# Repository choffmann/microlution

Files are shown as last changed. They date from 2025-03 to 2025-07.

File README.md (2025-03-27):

# Microlution

Vollautomatisierter Probenwechsler - ein haufen an Proben wird nach und nach in das Microskop befüllt,
welche automatisch abgelichtet werden und durch stiching aufgewertet werden.

- Display mit Fortschrittsbalken
- Buttons zum starten/stopen
- Stisching
  - hardwaremäßige abfahren
  - Bilder aufnehmen
  - In Software zusammensetzen
- Webserver
  - Zugriff auf Daten
  - Steuerung
  - Video Stream
- Besserer Autofocus
- Rust?

## Hardware

- microskope setup
- joystick
- taster
- Display
- (Vacum pumpe)
- extra stepper motoren

## Kommunikation

Discord
WhatsApp

## Code

GitHub -> Alles an Software
Workflow zum testen

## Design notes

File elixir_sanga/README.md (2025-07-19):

# ElixirSanga

Elixir library for communicating with the Sanga motor controller board via serial port.

## Communication Modes

This library supports two different communication modes:

### 1. Persistent Connection Mode (Fast, Exclusive Access)
Maintains a persistent connection to the serial port for high-frequency communication. This is faster but holds an exclusive lock on the serial port.

```elixir
# Start the persistent connection
{:ok, _pid} = Sanga.Board.start_link()

# Send commands
{:ok, version} = Sanga.Board.query("v")
{:ok, result} = Sanga.Board.multi_query(["n_motors 4", "mr 0 0 0 100", "n_motors 3"])
{:ok, result} = Sanga.Board.move_slider(100)

# Stop the connection
:ok = Sanga.Board.stop()
```

### 2. Safe Connection Mode (Slower, Shared Access)
Opens and closes the connection for each operation, allowing other services to access the serial port. This is slower due to connection overhead but allows multiple services to communicate with the motor controller.

```elixir
# No need to start/stop - each command manages its own connection
{:ok, version} = Sanga.Board.safe_query("v")
{:ok, result} = Sanga.Board.safe_multi_query(["n_motors 4", "mr 0 0 0 100", "n_motors 3"])
{:ok, result} = Sanga.Board.safe_move_slider(100)

# Stage control methods
{:ok, result} = Sanga.Board.safe_move_stage_x(10.5)    # Move stage in X direction
{:ok, result} = Sanga.Board.safe_move_stage_y(-5.2)    # Move stage in Y direction  
{:ok, result} = Sanga.Board.safe_move_stage_z(2.0)     # Move stage in Z direction
{:ok, result} = Sanga.Board.safe_release_stage()       # Release motor holding torque
{:ok, result} = Sanga.Board.safe_zero_stage()          # Zero/home the stage
```

### When to Use Each Mode

- **Persistent Mode**: Use when you need exclusive access and high-frequency communication
- **Safe Mode**: Use when other services also need to communicate with the motor controller

## Installation

If [available in Hex](https://hex.pm/docs/publish), the package can be installed
by adding `elixir_sanga` to your list of dependencies in `mix.exs`:

```elixir
def deps do
  [
    {:elixir_sanga, "~> 0.1.0"}
  ]
end
```

Documentation can be generated with [ExDoc](https://github.com/elixir-lang/ex_doc)
and published on [HexDocs](https://hexdocs.pm). Once published, the docs can
be found at <https://hexdocs.pm/elixir_sanga>.

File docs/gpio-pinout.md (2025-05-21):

| GPIO | Pin # | Funktion | Verwedt für | Schnittstelle |
| --- | ----- | --- | --- | --- |
| 3v3 Power | 1 | Stromversorgung | Rotary Encoder VCC | - |
| GND | 6 | Masse | Rotary Encoder GND | - |
| GPIO17 | 11 | Eingang | Rotary Encoder DT  | GPIO |
| GPIO18 | 12 | Eingang | Rotary Encoder CLK | GPIO |
| GPIO27 | 13 | Eingang | Rotary Encoder SW  | GPIO |
| 3v3 Power | 17 | Stromversorgung | TFT VCC | - |
| GND | 9 | Masse | TFT GND | - |
| GPIO10 | 19 | SPI MOSI | TFT MOSI | SPI |
| GPIO11 | 23 | SPI SCK | TFT SCK | SPI |
| GPIO16 | 36 | Ausgang | TFT Backlight LED  | GPIO |
| GPIO9 | 21 | SPI MISO | TFT MISO | SPI |
| GPIO24 | 18 | Ausgang | TFT DC | GPIO |
| GPIO25 | 22 | Ausgang | TFT RST | GPIO |
| GPIO8 | 24 | SPI CS0 | TFT CS | SPI |
| GPIO 14 | 8 | UART TX | Sangaboard | UART |
| GPIO 15 | 10 | UART RX | Sangaboard | UART |

Mögliche Konflikte mit dem Sangaboard:

- **GPIO24** und **GPIO25** sind nur dann zu verwenden, wenn keine Firmware-Upgrades für das Sangaboard geplant sind.
- **GPIO14** und **GPIO15** (UART) sollten nicht verwendet werden, diese sind für die Kommunikation mit dem Sangaboard reserviert.

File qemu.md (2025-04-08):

```bash
# mount /boot
sudo mount -o loop,offset=4194304 2023-04-13-raspbian-openflexure-buster-armhf.img /mnt/rpi-boot
# mount /
sudo mount -v -o offset=266338304 -t ext4 2023-04-13-raspbian-openflexure-buster-armhf.img /mnt/rpi-boot
```

offset => `fdisk -l <img>` => anfang _einheit sektoren. (8192_ 512 = 4194304)

Weitere benötigte Dateien, welche in /boot zu finden sind:

- `bcm2710-rpi-3-b.dtb`
- `kernel8.img`

### User password reset

`/` von img mounten und in `/etc/passwd` das `...:x:...` entfernen. Das entfernen von `:x:` entfernt das kennwort vom benutzer.

```bash
# root:x:0:0:root:/root:/bin/bash
#      ^--- entfernen
# root::0:0:root:/root:/bin/bash
```

## QEMU

`CTRL-a + c` => qemu console
`CTRL-a + x` => qemu terminate
`system_powerdown` => shutdown guest

Resize img für qemu (qemu mag anscheind nur images in der größe `^2`)

```bash
qemu-img resize 2023-04-13-raspbian-openflexure-buster-armhf.img 8G
```

Image Partition muss dennoch angepasst werden

```bash
qemu-system-aarch64 \
    -machine raspi3b \
    -cpu cortex-a72 \
    -nographic \
    -m 1G \
    -smp 4 \
    -dtb bcm2710-rpi-3-b.dtb \
    -kernel kernel8.img \
    -append "rw earlyprintk loglevel=8 console=ttyAMA0,115200 dwc_otg.lpm_enable=0 root=/dev/mmcblk0p2 rootdelay=1" \
    -netdev user,id=net0,hostfwd=tcp::5000-:5000,hostfwd=tcp::2222-:22 \
    -device usb-net,netdev=net0 \
    -device usb-host,hostbus=5,hostaddr=6 \
    -sd 2023-04-13-raspbian-openflexure-buster-armhf.img
```

### Resize partitions

```bash
sudo fdisk /dev/mmcblk0
```

```
Command (m for help): d
Partition number (1,2, default 2): 2
Partition 2 has been deleted.

Command (m for help): n
Partition type
   p   primary (1 primary, 0 extended, 3 free)
   e   extended (container for logical partitions)
Select (default p): e
Partition number (2-4, default 2): 2
First sector (2048-16777215, default 2048): 520192
Last sector, +/-sectors or +/-size{K,M,G,T,P} (520192-16777215, default 16777215):

Created a new partition 2 of type 'Extended' and of size 7.8 GiB.
Partition #2 contains a ext4 signature.

Do you want to remove the signature? [Y]es/[N]o: n
```

```bash
sudo resize2fs /dev/mmcblk0p2
```

## OpenFlexure Server in qemu

mit `DummyCamera` kann `vchiq` (Pi Kamera) umgehen und `DummyStage` (Motoren) deaktiviert werden.

```json
{
  "camera": {
    "type": "DummyCamera"
  },
  "stage": {
    "type": "DummyStage",
    "port": null
  }
}
```

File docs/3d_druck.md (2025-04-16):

# Tracking of 3d printed parts

## Original Parts [download link](https://build.openflexure.org/openflexure-microscope/v7.0.0-beta3/source.zip)
| Part Name | Required Quantity | Printed Quantity | File | Extra Details |
|---|---|---|---|---|
| Actuator assembly tools (nut tool, band tool, and band tool cover) | 1 | - | [actuator_assembly_tools.stl] | |
| Lens tool | 1 | - | [lens_tool.stl] | |
| Main body | 1 | 1 | [main_body.stl] | The smart brim may require custom print settings. |
| Cable tidy caps | 3 | - | [cable_tidies.stl] | |
| Sample clips | 2 | - | [sample_clips.stl] | |
| Microscope stand | 1 | 1 | [microscope_stand.stl] | |
| Electronics drawer | 1 | - | [electronics_drawer-pi4_sanga_stack_11mm.stl] | For Pi 4 and HAT-style Sangaboard with 11mm tall headers. For other combinations, refer to customization page |
| Small gears | 3 | - | [small_gears.stl] | |
| Illumination dovetail | 1 | - | [illumination_dovetail.stl] | |
| Condenser arm | 1 | - | [condenser.stl] | |
| Condenser board spacer | 1 | - | [condenser_board_spacer.stl] | |
| Condenser lid | 1 | - | [condenser_lid.stl] | |
| Illumination thumbscrew | 1 | - | [illumination_thumbscrew.stl] | |
| Large gears | 3 | - | [large_gears.stl] | |
| Feet | 3 | - | [feet.stl] | |
| Optics module | 1 | - | [optics_picamera_2_rms_f50d13.stl] | Must be printed in black! |
| Pi camera cover | 1 | - | [picamera_2_cover.stl] | |

## Modified Parts

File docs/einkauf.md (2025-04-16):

# Liste an bestellten Teilen
## Bestellung 1
| Item | Quantity | angekommen | Link |
|---|---|---|---|
| **Shop1** | | | |
| Nema17 | 1 | - [ ] | [Link](https://www.roboter-bausatz.de/p/act-nema-17-schrittmotor-17hs3404l23p1-x1-12v-0.4a-34mm) |
| TMC2209 Stepper Driver | 1 | - [ ] | [Link](https://www.roboter-bausatz.de/p/mks-tmc2209-schrittmotortreiber) |
| Vierkant Mutter | 20? | - [ ] | [Link](https://www.roboter-bausatz.de/p/m3-vierkantmutter-5-5x2-5mm) |
| belt | 1 | - [ ] | [Link](https://www.roboter-bausatz.de/p/yourdroid-gt2-zahnriemen-offen-6mm-1-meter-faserverstaerkt) |
| motor pulley | 1 | - [ ] | [Link](https://www.roboter-bausatz.de/p/gt2-riemenscheibe-20-zaehne-5mm-bohrung-fuer-6mm-riemen) |
| idler pulley | 1 | - [ ] | [Link](https://www.roboter-bausatz.de/p/gt2-zahnriemen-flachriemenscheibe-3mm-bohrung-fuer-6mm-zahnriemen) |
| Display 2,4 Zoll | 1 | - [ ] | [Link](https://www.roboter-bausatz.de/p/2-4-tft-lcd-display-modul-ili9341-240x320) |
| Rotaryencoder | 1 | - [ ] | [Link](https://www.roboter-bausatz.de/p/drehencoder-drehregler-ky-040-modul) |
| Navigation module | 1 | - [ ] | [Link](https://www.roboter-bausatz.de/p/joystick-5-richtungen-navigation-button-modul) |
| mosfet modul | 2 | - [ ] | [Link](https://www.roboter-bausatz.de/p/mosfet-irf520-treibermodul) |
| jumper kabel | 1 | - [ ] | [Link](https://www.roboter-bausatz.de/p/dupont-jumper-kabel-3-x-40-pin-20-cm-m2m-f2m-f2f) |
| **Shop2** | | | |
| Elektromagnet 20x15 | 4 | - [ ] | [Link](https://funduinoshop.com/elektronische-module/sonstige/elektromagnete/elektromagnet-dc12v-wf-p20/15-2-5kg) |

## Bestellung 2
Noch nichts geplant.  
Dient um Teile nachzukaufen die im Laufe des Projektes als Notwendig erkannt werden.

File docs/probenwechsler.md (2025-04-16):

# Doku des Probenwechslers
## Ursprünglicher Zustand
Proben werden per Hand auf der Stage platziert. Proben werden mit Clips fixiert an der Stage. Und danach per Hand entfernt.
## Gewünschter Zustand
Ein System das mehrere (ung.2-5) 75x25mm Proben über die Stage bewegt. Die Bewegung passiert automatisiert. 

## Herausforderungen
1. Bewegung der Stage darf nicht eingeschränkt werden
2. Probenarretierung
3. Motorsteuerung
4. OpenSCAD

## Designs
1. Slide befestigt an Stage (ersetzt wahrscheinlich keine der achsen, bewegung vorne/hinten benutzt x und y motor)
2. Magazin mit Bewegungsarm. Bewegt einzelne Proben von einem Magazin auf die Stage und weg.
3. Magazin mit Dreharm

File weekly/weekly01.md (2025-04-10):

---
date: 10.04.2025
---

## Stitching #1

@fiete

**Recherche**

Es gibt zwei optionen

- Automatische kantenerkennung
- Manuelle zusammenfügeng durch x und y werte + kanten aufweichen (feathering, blending)

Wie implementieren wenn kein null punkt möglich? Beides verwenden?

Andere variante für Nullpunkt wäre das erste Bild von dem man aus geht

**Nächster Schritt**

- [ ] Beispieldaten: Ziehen oder manuell erstellen?

## Einkauf #8

@niklas

Bestellliste wurde ertsellt, wird noch überarbeitet <https://docs.google.com/spreadsheets/d/19g0L3icq9huzQc2gaac8i5vfSKruxdHDz61IX5RrIJk/edit?usp=sharing>

## Gesamtsystem

@cedrik

System wurde testweise aufgesetzt (emuliert in qemu, da kein Pi zur verfügung), sowie generelle recherche zum System

**Nächster Schritt**

- [ ] Software aufsetzen auf einem Pi
- [ ] Microsope drucken und bauen

## Probenwechsler #4

@niklas

Erster Prototyp wurde erstellt, kleine Magnete sind schwach, große Magnete sind zu groß.

**Nächster Schritt**

- [ ] 3D Sourcefile vom Microsope anpassen für unser System
- [ ] Mit echte Probe austesten zu heben

## Organisation

@alle

- [ ] Noch nicht zugeteilte aufgaben zuteilen

## Hardware Input #11

Noch nicht gestartet

## Web UI #13

Noch nicht gestartet

## Webserver #9

Noch nicht gestartet

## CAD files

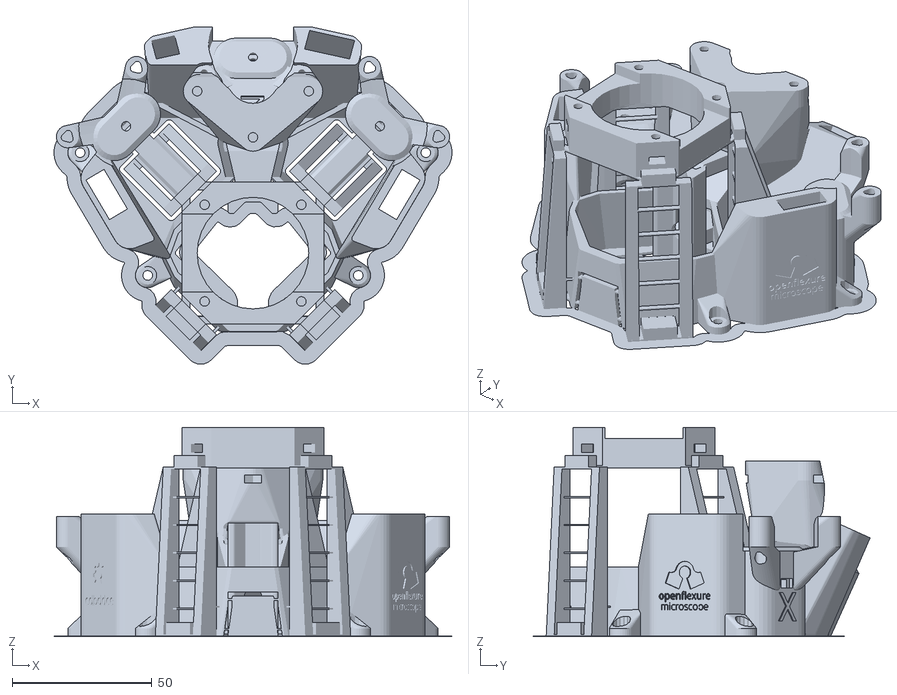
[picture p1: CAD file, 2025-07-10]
custom-stl-parts/openflexure_body_modified.stl
142.6 x 120.9 x 75.0

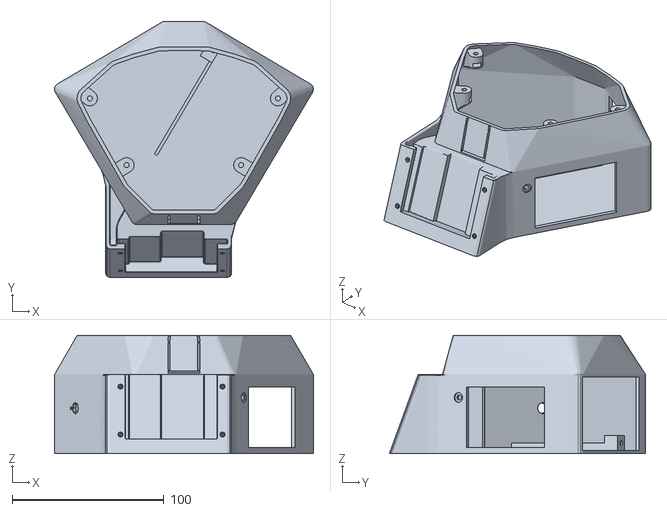
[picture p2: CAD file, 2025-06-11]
custom-stl-parts/microscope_stand_jw_v2.stl
170.6 x 168.9 x 78.0

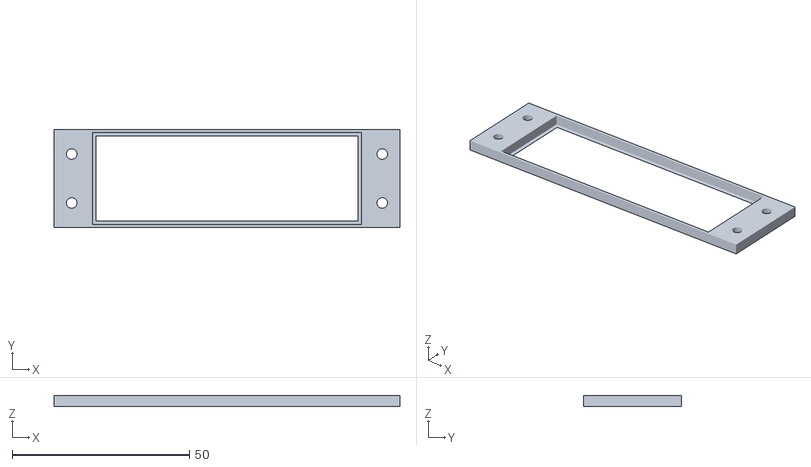
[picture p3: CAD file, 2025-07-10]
custom-stl-parts/MicroSlide/MicroSlide_follower_sample holder.stl
97.6 x 27.6 x 3.10

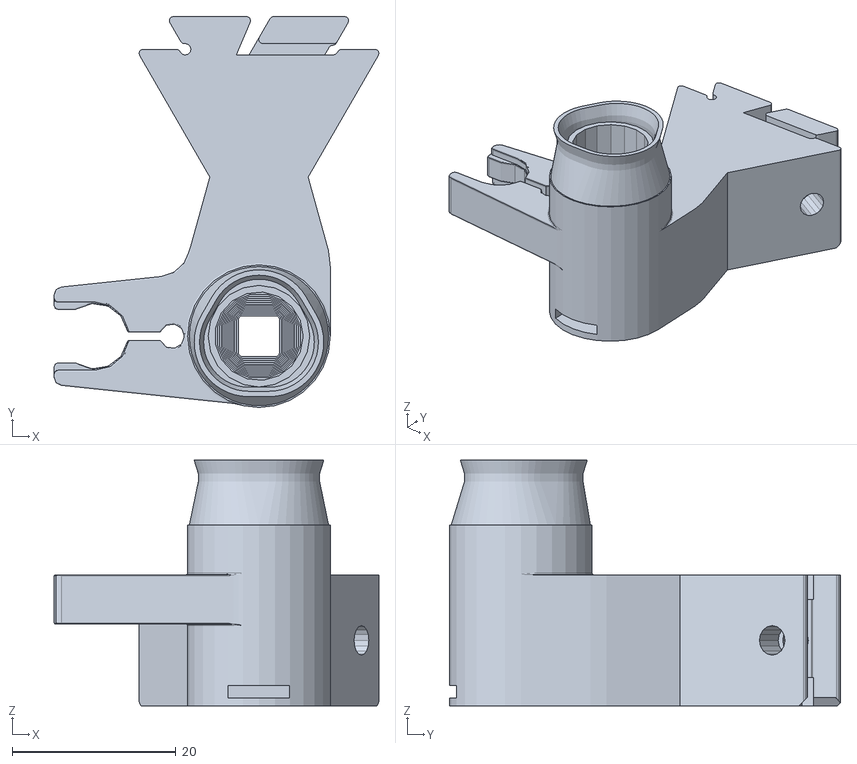
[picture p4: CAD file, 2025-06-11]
custom-stl-parts/condensersolid.stl
39.6 x 47.7 x 30.0

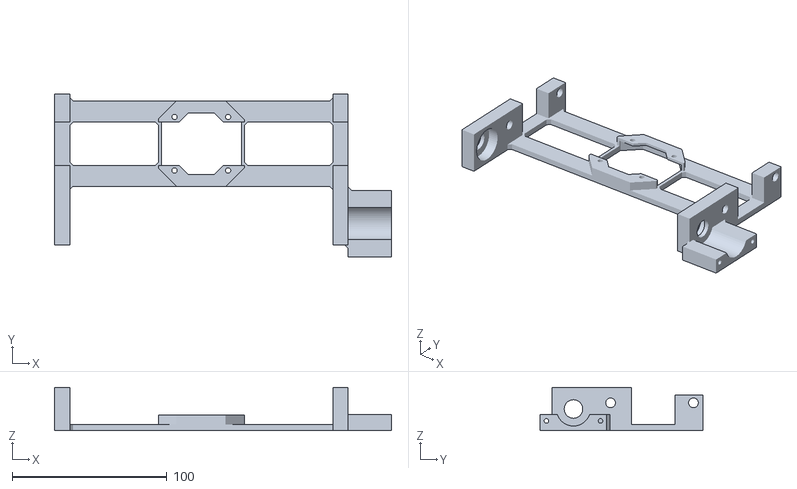
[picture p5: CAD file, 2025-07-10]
custom-stl-parts/MicroSlide/MicroSlide_Platformbracket.stl
218.0 x 105.1 x 28.0

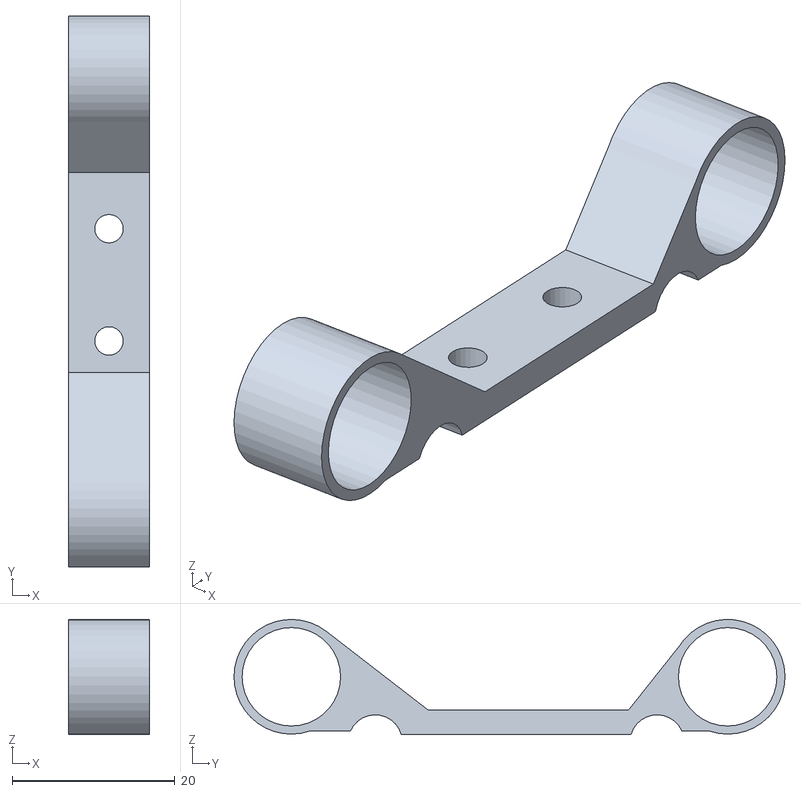
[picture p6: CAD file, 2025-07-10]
custom-stl-parts/MicroSlide/MicroSlide_follower_stabilizer.stl
10.0 x 67.7 x 14.1

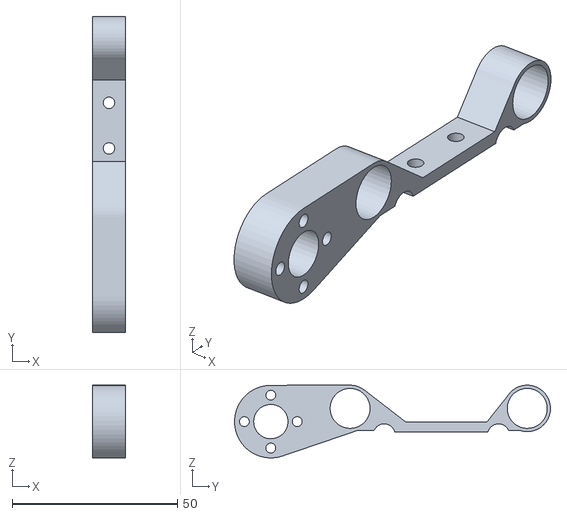
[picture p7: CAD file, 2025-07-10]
custom-stl-parts/MicroSlide/MicroSlide_follower_screw_connection.stl
10.0 x 95.7 x 22.0

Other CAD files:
CAD-Designs/MicroSlide v6 (Fusion360).f3z

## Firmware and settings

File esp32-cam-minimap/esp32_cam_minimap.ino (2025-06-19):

#include "esp_camera.h"
#include <WiFi.h>
#include <WebServer.h>

const char* ssid = "Microlution";
const char* password = "knorke123";

WiFiClient streamClient;
bool isStreaming = false;

// Set camera model (AI Thinker)
#define PWDN_GPIO_NUM     32
#define RESET_GPIO_NUM    -1
#define XCLK_GPIO_NUM      0
#define SIOD_GPIO_NUM     26
#define SIOC_GPIO_NUM     27

#define Y9_GPIO_NUM       35
#define Y8_GPIO_NUM       34
#define Y7_GPIO_NUM       39
#define Y6_GPIO_NUM       36
#define Y5_GPIO_NUM       21
#define Y4_GPIO_NUM       19
#define Y3_GPIO_NUM       18
#define Y2_GPIO_NUM        5
#define VSYNC_GPIO_NUM    25
#define HREF_GPIO_NUM     23
#define PCLK_GPIO_NUM     22

WebServer server(80);

void startCamera() {
  camera_config_t config;
  config.ledc_channel = LEDC_CHANNEL_0;
  config.ledc_timer = LEDC_TIMER_0;
  config.pin_d0 = Y2_GPIO_NUM;
  config.pin_d1 = Y3_GPIO_NUM;
  config.pin_d2 = Y4_GPIO_NUM;
  config.pin_d3 = Y5_GPIO_NUM;
  config.pin_d4 = Y6_GPIO_NUM;
  config.pin_d5 = Y7_GPIO_NUM;
  config.pin_d6 = Y8_GPIO_NUM;
  config.pin_d7 = Y9_GPIO_NUM;
  config.pin_xclk = XCLK_GPIO_NUM;
  config.pin_pclk = PCLK_GPIO_NUM;
  config.pin_vsync = VSYNC_GPIO_NUM;
  config.pin_href = HREF_GPIO_NUM;
  config.pin_sscb_sda = SIOD_GPIO_NUM;
  config.pin_sscb_scl = SIOC_GPIO_NUM;
  config.pin_pwdn = PWDN_GPIO_NUM;
  config.pin_reset = RESET_GPIO_NUM;
  config.xclk_freq_hz = 20000000;
  config.pixel_format = PIXFORMAT_JPEG;

  config.frame_size = FRAMESIZE_QVGA;
  config.jpeg_quality = 10;
  config.fb_count = 2;

  esp_err_t err = esp_camera_init(&config);
  if (err != ESP_OK) {
    while (true) delay(1000);
  }
}

void stream() {
  streamClient = server.client();
  isStreaming = true;

  String response = "HTTP/1.1 200 OK\r\n";
  response += "Content-Type: multipart/x-mixed-replace; boundary=frame\r\n\r\n";
  streamClient.print(response);
}

void capture() {
  camera_fb_t *frameBuffer = esp_camera_fb_get();
  if (!frameBuffer) {
    server.send(500, "text/plain", "Camera capture failed");
    return;
  }

  server.setContentLength(frameBuffer->len);
  server.send(200, "image/jpeg", "");

  WiFiClient client = server.client();
  client.write(frameBuffer->buf, frameBuffer->len);

  esp_camera_fb_return(frameBuffer);
}

void setup() {
  Serial.begin(115200);
  delay(1000);

  WiFi.begin(ssid, password);
  while (WiFi.status() != WL_CONNECTED) {
    delay(500);
  }


  startCamera();

  server.on("/stream", HTTP_GET, stream);
  server.on("/capture", HTTP_GET, capture);
  server.begin();
}

void loop() {
  server.handleClient();

  if (isStreaming && streamClient.connected()) {
    camera_fb_t *frameBuffer = esp_camera_fb_get();
    if (frameBuffer) {
      streamClient.write(frameBuffer->buf, frameBuffer->len);
      esp_camera_fb_return(frameBuffer);
    }
    delay(100);
  } else if (isStreaming) {
    isStreaming = false;
  }
}

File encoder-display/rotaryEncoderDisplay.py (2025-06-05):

import RPi.GPIO as GPIO
import time
import requests
import board
import busio
import digitalio
import displayio
from adafruit_ili9341 import ILI9341
from adafruit_display_text import label
import terminalio

displayio.release_displays()

# GPIO-Pin-Config Roatary encoder
CLK = 17
DT = 18
SW = 27

# OpenFlexure Server URL
URL = "http://localhost:5000/api/v2/actions/stage/move/"
STEP_SIZES = {'z': 200, 'x': 200, 'y': 200}

# SPI-Setup
spi = busio.SPI(clock=board.SCK, MOSI=board.MOSI)

backlight = digitalio.DigitalInOut(board.D16)
backlight.direction = digitalio.Direction.OUTPUT
backlight.value = True

display_bus = displayio.FourWire(
    spi,
    command=board.D24,
    chip_select=board.D8,
    reset=board.D25
)

display = ILI9341(display_bus, width=320, height=240, rotation= 180)

# GUI
splash = displayio.Group()
display.root_group = splash

# Achse-Label
label_static = label.Label(
    terminalio.FONT,
    text="Achse: ",
    color=0xFFFFFF,
    x=260,
    y=10
)

# Achsen-Kennung
label_dynamic = label.Label(
    terminalio.FONT,
    text="Z",
    color=0xFFFFFF,
    background_color=0x0000FF,
    x=300,
    y=10
)

splash.append(label_static)
splash.append(label_dynamic)

mode_colors = {'z': 0x0000FF, 'x': 0x00AA00, 'y': 0xFF0000}

# GPIO Setup Rotary-Encoder
GPIO.setmode(GPIO.BCM)
GPIO.setup(CLK, GPIO.IN, pull_up_down=GPIO.PUD_UP)
GPIO.setup(DT, GPIO.IN, pull_up_down=GPIO.PUD_UP)
GPIO.setup(SW, GPIO.IN, pull_up_down=GPIO.PUD_UP)

last_clk_state = GPIO.input(CLK)
modes = ['z', 'x', 'y']
mode_index = 0

print(f"Aktueller Modus: {modes[mode_index].upper()}")

def update_display_mode():
    axis = modes[mode_index]
    label_dynamic.text = axis.upper()
    label_dynamic.background_color = mode_colors[axis]

def move_axis(axis, amount):
    payload = {axis: amount, 'absolute': False}
    try:
        response = requests.post(URL, json=payload, timeout=1)
        if response.status_code == 201:
            print(f"{axis.upper()} bewegt um {amount} – Antwort: {response.json()}")
        else:
            print(f"Fehlerhafte Antwort ({response.status_code}): {response.text}")
    except requests.exceptions.RequestException as e:
        print("API-Fehler:", e)

def button_callback(channel):
    global mode_index
    mode_index = (mode_index + 1) % len(modes)
    print(f"Modus gewechselt: {modes[mode_index].upper()}")
    update_display_mode()

GPIO.add_event_detect(SW, GPIO.FALLING, callback=button_callback, bouncetime=300)

try:
    while True:
        clk_state = GPIO.input(CLK)
        dt_state = GPIO.input(DT)

        if clk_state != last_clk_state and clk_state == GPIO.HIGH:
            if dt_state != clk_state:
                move_axis(modes[mode_index], STEP_SIZES[modes[mode_index]])
            else:
                move_axis(modes[mode_index], -STEP_SIZES[modes[mode_index]])
            time.sleep(0.02)  # Entprellung

        last_clk_state = clk_state
        time.sleep(0.001)

except KeyboardInterrupt:
    print("Beendet")
    GPIO.cleanup()
    splash.pop()

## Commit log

2025-06-02 feat: implement ili9341 display and spi interface
2025-06-05 encoder-display script
2025-06-11 modified microscope parts
    [condensersolid.stl, microscope_stand_jw_v2.stl]
2025-06-18 feat: enable rotary encoder
2025-06-18 feat: implement rotary encoder
2025-06-19 feat: change rotary encoder implementation
2025-06-19 Change IP-Adress for esp32-cam
2025-06-19 Add esp32 cam code for minimap
2025-07-05 Clean up board methods
2025-07-08 Add sanga board method for moving multiple axes
2025-07-10 Add design and mesh files for MicroSlide
    [MicroSlide v6 (Fusion360).f3z, MicroSlide_Platformbracket.stl, MicroSlide_follower_sample holder.stl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]
2025-07-11 Fix minimap movement blocked by uart info message
2025-07-14 Various Changes
    - Implement Sanga boundaries
    - Add toggle for show minimap features
    - Add Navigation for Minimap
    - Add Button to move slider to center of camera
    - Add Focus Boundary movement
2025-07-19 Add button to set boundary sanga start
2025-07-21 feat: run poll input event in other thread
2025-07-21 fix: control mode section
    [main.rs]
2025-07-21 fix: remove interval refetches
    [main.rs]
